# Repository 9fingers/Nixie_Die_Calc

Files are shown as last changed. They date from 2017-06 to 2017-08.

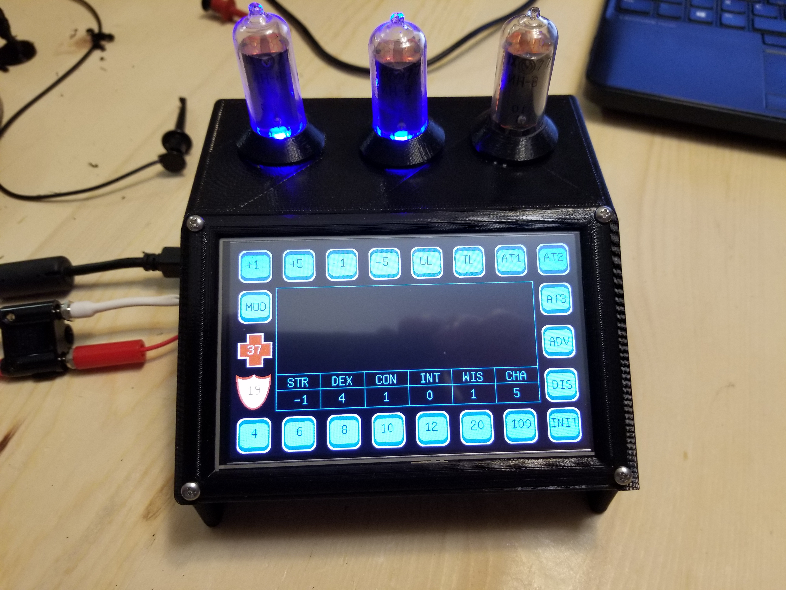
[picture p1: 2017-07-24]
20170722_200715[1].jpg

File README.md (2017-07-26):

# Nixie_Die_Calc<br />
An Arduino 2560 controlled die calculator that uses a 5.0" TFT for inputs, and displays the results on eh screen, and Nixie tubes. 

TFT control sketch is using the stock Adafrtuit RA8875 library.<br />

Videos of the project in its different states of flux. If you are curious as to how it functions watch the videos.https://www.youtube.com/user/BrnChknBrnCow

Hardware compatibility <br />
Nixie IN-18 <br />
IC 74141 Nixie control 16 pin chips<br />
Arduino MEGA 2560<br />
Adafruuit RA8875 Driver Chip (Part # 1590)<br />
Adafruit 5.0" TFT (800x480) (Part # 1596)<br />
Adafruit MicroSD card breakout board+ (Part # 254)<br />
<br />
Mentions:<br />
Nathaniel Burger: Software engineering manager.<br />
Assisted early on in the project by helping to explain the different building blocks while writing the code. Functions, variables (global and local), and plenty of other pointers that I failed to grasp at the time.

Cody Tappan: Embedded systems engineer. <br />
His code is commented in the project. Assisted with cursor tracking, and mapping the touch screen. 1024x1024 touch interface over a rectangular screen. 

Elliot Due: Electrical Engineer.<br />
Assisted with features that I decided to remove from the project as the scope of the project changed, and they were no longer needed. I learned a lot about board design, and reading electronics schematics. 

Eli Delia: Entrepreneur, graphics designer, jack of all trades.<br />
Modeled the dragon head for the final build. Introduced me to Fusion 360, and is defining the 3D print jobs for the final build. 

Last but not least, Conor Mooreman: Muse<br />
Conor was my inspiration to start this project, and to see it through to completion. So many times I have started projects like this and not completed them. Am truly happy to have this one so close to completion, can't wait for him to be able to try to use this. Conor has limited mobility, and dexterity, thus he cannot retrieve dice once they are rolled. He was using an app to roll dice which is just....well....boring. Hence the Nixie Die Calculator was born.</br>
</br>
</br>
</br>
On a side note this system can be used without the tubes, and only the touch screen display, and the SD card. 

Multiple web forums and thier contributors. <br />
Adafruit forums<br />
Arduino forums<br />
http://overskill.alexshu.com/saving-loading-settings-on-sd-card-with-arduino/

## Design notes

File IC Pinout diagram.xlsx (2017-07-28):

INPUT | INPUT | INPUT | INPUT | Lights | Wire
A | B | C | D | Cathode | Color
L | L | L | L | 0 | black
H | L | L | L | 1 | brown
L | H | L | L | 2 | red
H | H | L | L | 3 | orange
L | L | H | L | 4 | yellow
H | L | H | L | 5 | green
L | H | H | L | 6 | blue
H | H | H | L | 7 | purple
L | L | L | H | 8 | grey
H | L | L | H | 9 | white
10k Resistor to +180Vdc |  |  |  | Anode | grey
Wire Color | BLACK | BROWN | GREEN | YELLOW |  | BLUE | PURPLE | ORANGE
Nixie #'s | 0 | 1 | 5 | 4 | GND | 6 | 7 | 3
Chip Pins | 16 | 15 | 14 | 13 | 12 | 11 | 10 | 9
 | 74141
Chip Pins | 1 | 2 | 3 | 4 | 5 | 6 | 7 | 8
Nixie #'s | 8 | 9 | A | D | Vcc +3.3 | B | C | 2
Wire Color | GREY | WHITE |  |  |  |  |  | RED

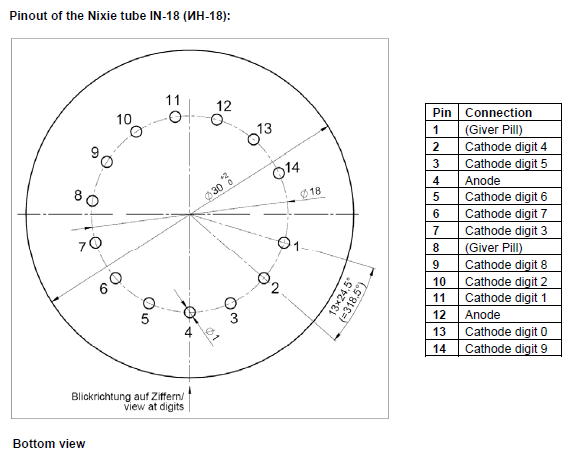
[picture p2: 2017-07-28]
in-18 Pinout.png

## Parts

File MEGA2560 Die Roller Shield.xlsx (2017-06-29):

Comment | Description | Designator | Footprint | LibRef | Quantity
AD_H |  | AD_H1 | Header 8x1 8.5mm | AD_H | 1
AD_L |  | AD_L1 | Header 8x1 8.5mm | AD_L | 1
Cap1 | Capacitor | C1, C4, C5, C8 | RAD-0.3 | Cap1 | 4
Cap2 | Capacitor | C2, C3, C6, C7 | CAPR5-4X5 | Cap2 | 4
Communication |  | COMMS1 | Header 8x1 8.5mm | Communication | 1
30V Zener | 1N5363B-TP | D1, D4 | Zener Diode | D Zener 30v 5w | 2
1N4002RLG | High Conductance Fast Diode | D2, D3, D5, D6 | DIODE | Diode 1N4002RLG | 4
1N4148 | High Conductance Fast Diode | D7 | DIODE | Diode 1N4148 | 1
IO_36 |  | DIGITAL1 | HEADER 36X 8MM | IO_36 | 1
ICSP |  | ICSP1 | ICSP | ICSP | 1
Relay-NL | TX2-L-3V | K1 | MODULE6 | Relay-DPST | 1
Header 13 | Header, 13-Pin | P1, P2, P3 | HDR1X13 | Header 13 | 3
Header 18X2 | Header, 18-Pin, Dual row | P4 | HDR2X18 | Header 18X2 | 1
Header 2 | Header, 2-Pin | P5 | HDR1X2 | Header 2 | 1
Header 3 | Header, 3-Pin | P6 | HDR1X3 | Header 3 | 1
Eye output | Header, 6-Pin | P7, P11 | HDR1X6 | Header 6 | 2
6.3 VDC HEATER POWER | Header, 2-Pin | P9 | HDR1X2 | Header 2 | 1
POWER |  | POWER1 | Header 6x1 8.5mm | POWER | 1
PWM_H |  | PWM_H1 | Header 8x1 8.5mm | PWM_H | 1
PWM_L |  | PWM_L1 | Header 8x1 8.5mm | PWM_L | 1
SS9014ABU-ND | SS9014ABU-ND | Q1, Q2 | TO-226-AA | Transistor 45V 0.1A | 2
TX2-L-3V | TX2-L-3V | Q3 | TO-226-AA | Transistor 45V 0.1A | 1
Res1 | Resistor, Resistor, Resistor, RES 2.7K OHM 1W 5% AXIAL, RES 2.7K OHM 1W 5% AXIAL | R1, R2, R5, R16, R26 | AXIAL-0.3 | Res1 | 5
Res2 | Resistor, Resistor, Resistor, RES 47k OHM 1W 5% AXIAL, RES 47k OHM 1W 5% AXIAL | R3, R4, R6, R9, R19 | AXIAL-0.3 | Res1, Res1, Res1, Res2, Res2 | 5
Res4 | RES 220k Ohm ±5% 1W | R7, R11, R17, R21 | AXIAL-0.3 - 220K | Res4 | 4
Res5 | RES 1M OHM 1W 5% AXIAL | R8, R10, R13, R18, R20, R23 | AXIAL-0.3 | Res5 | 6
RPot2 | 200k Ohm 0.5W, 1/2W Through Hole Thumbwheel Potentiometer Top Adjustment | R12, R22 | VR5-Top View | RPot2 | 2
RPot1 | 5k Ohm 0.5W, 1/2W Through Hole Thumbwheel Potentiometer Side Adjustment | R14, R25 | VR5 | RPot1 | 2
Res3 | RES 100k Ohm ±5% 0.25W, 1/4W | R15, R24 | AXIAL-0.3 | Res3 | 2
Res7 | RES 10k OHM .25W 5% AXIAL | R27 | AXIAL-0.3 | Res7 | 1
Res6 | RES 1k OHM .25W 5% AXIAL | R28 | AXIAL-0.3 | Res6 | 1
74141 | 16 Pin Dip Socket | U1, U2, U3 | PDIP16 | 74141 | 3

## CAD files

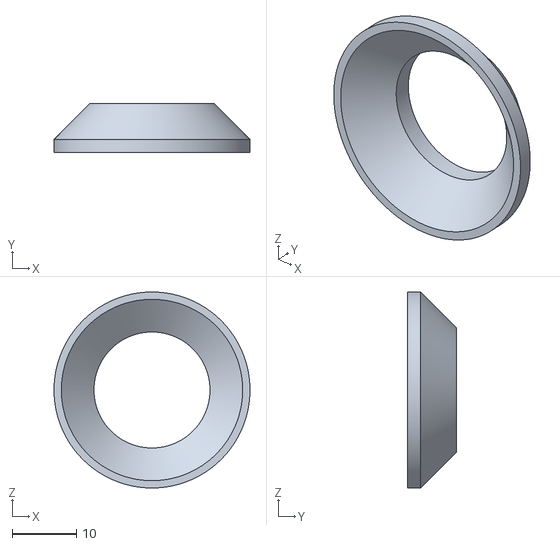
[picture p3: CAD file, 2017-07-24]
Tube Cone.stl
30.5 x 7.62 x 30.5

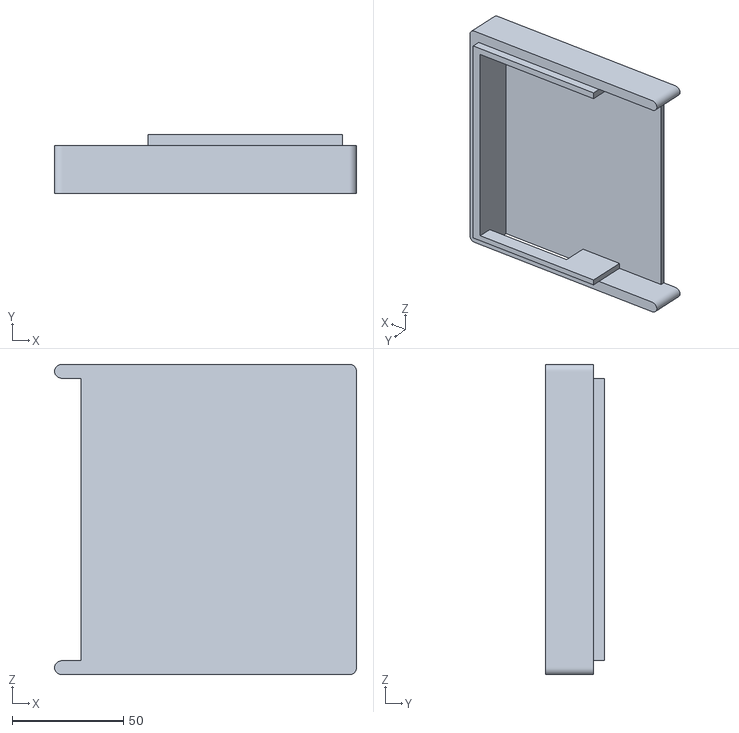
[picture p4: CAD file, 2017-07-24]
TFT Base.stl
135.9 x 26.7 x 139.7

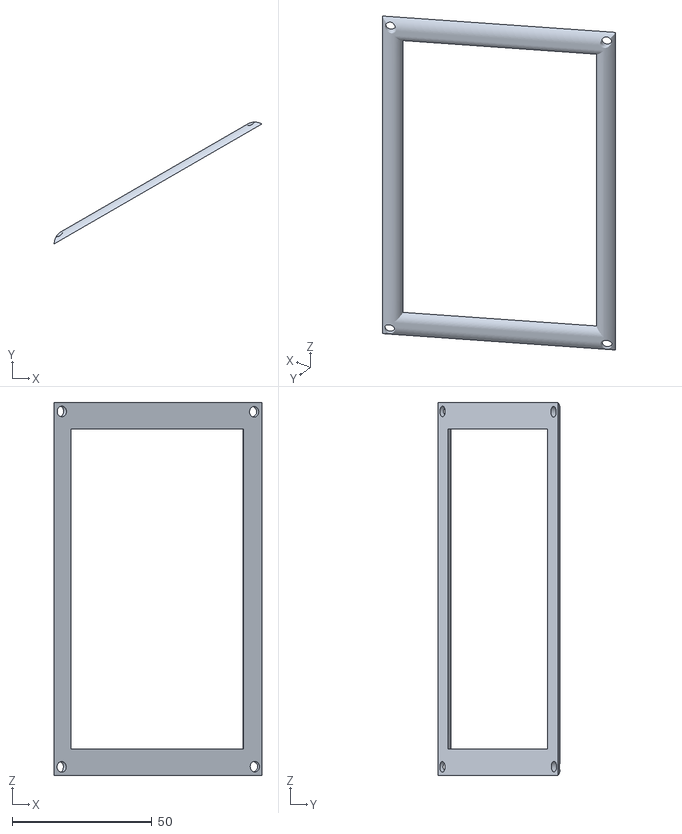
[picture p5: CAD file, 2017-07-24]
Bezel.stl
74.2 x 43.5 x 133.3

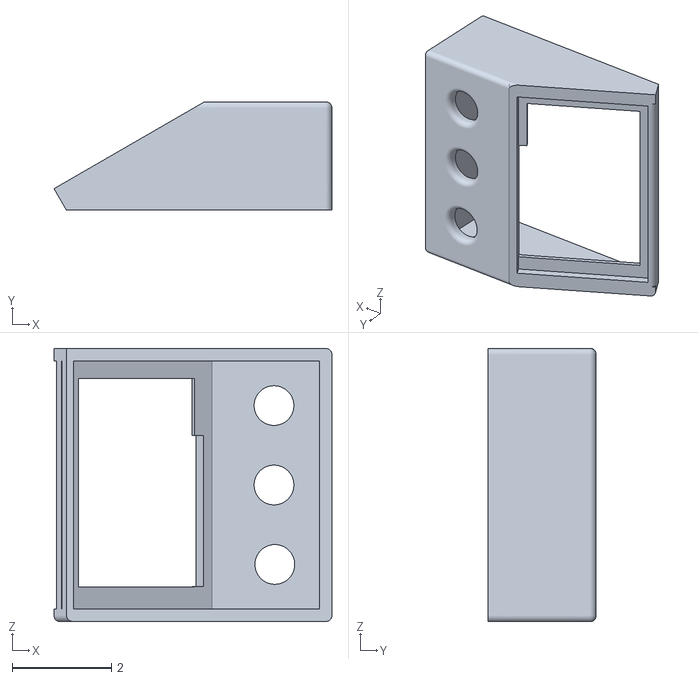
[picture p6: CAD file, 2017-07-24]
TFT Mount v3.stl
5.60 x 2.18 x 5.50

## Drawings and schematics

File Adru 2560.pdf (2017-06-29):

1

2

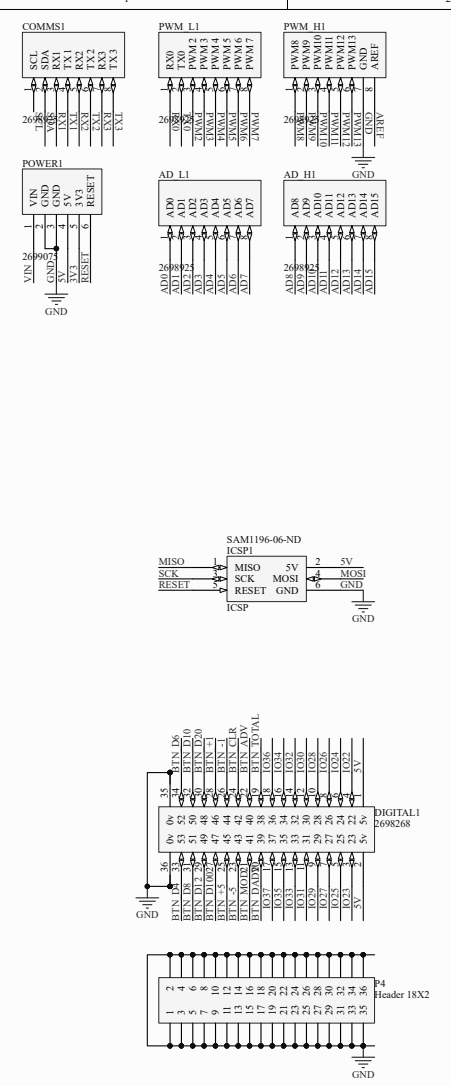
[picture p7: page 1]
VIN; GND; RESET; SCL; SDA; PWM2; PWM3; PWM4; PWM5; PWM6; PWM7; PWM8; PWM9; PWM10; PWM11; PWM12; PWM13; AREF; BTN_D6; BTN_D10; BTN_D20 BTN_+1 BTN_-1; BTN_CLR; BTN_ADV; BTN_TOTAL; BTN_D8; BTN_D12; BTN_D100 BTN_+5 BTN_-5; BTN_MOD; BTN_DADV; MISO 1; SCK 3; MOSI; RESET 5; SAM1196-06-ND ICSP1; ICSP; MISO SCK RESET; 5V MOSI GND; VIN 1; GND 2; GND 3 5V 4; RESET 6; POWER1; SCL 1; SDA 2 RX1 3; COMMS1; PWM 2 3; PWM 3 4; PWM 4 5; PWM 5 6; PWM 6 7; PWM 7 8; PWM_L1; PWM8 1; PWM9 2; PWM10 3 PWM11 4; PWM12 5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

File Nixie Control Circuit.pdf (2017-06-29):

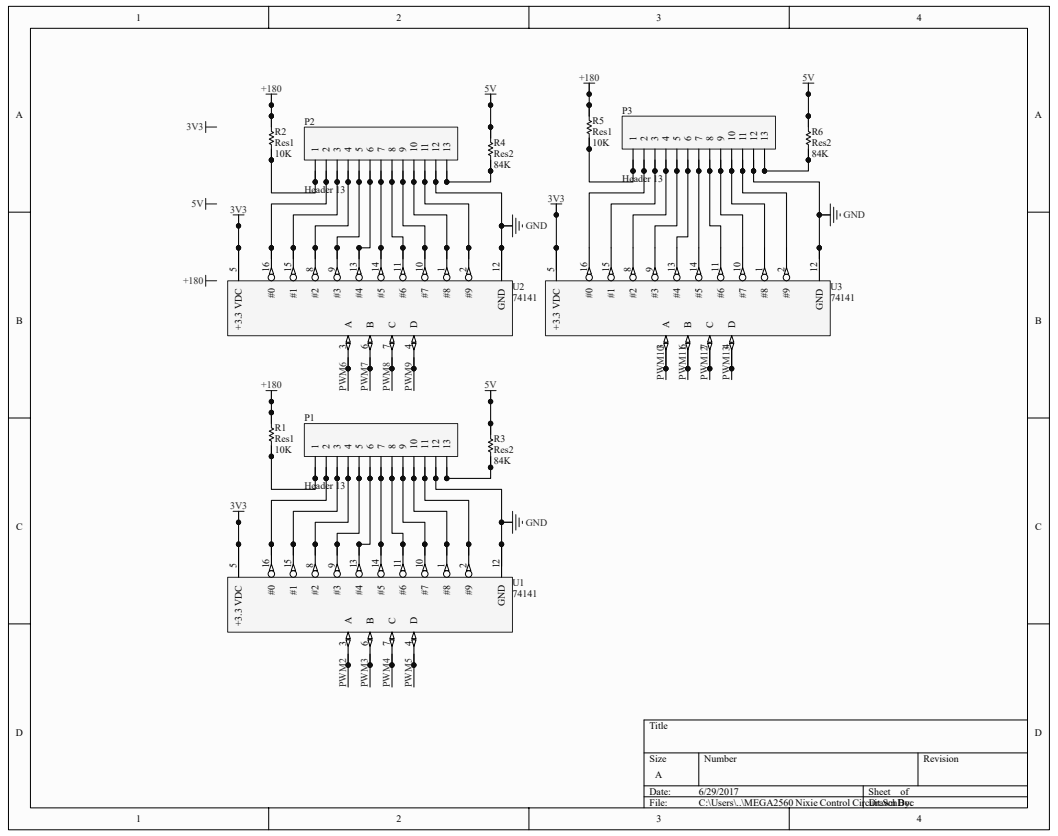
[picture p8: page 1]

Size A | Number | Revision

Date: 6/29/2017 | Sheet of
File: C:\Users\..\MEGA2560 Nixie Control Circuit.SchDoc Drawn By:

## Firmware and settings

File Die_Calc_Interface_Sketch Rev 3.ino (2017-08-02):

/******************************************************************
  This is an example for the Adafruit RA8875 Driver board for TFT displays
  ---------------> http://www.adafruit.com/products/1590
  It is tested to work with displays in the Adafruit shop. Other displays
  may need timing adjustments and are not guanteed to work.

  Adafruit invests time and resources providing this open
  source code, please support Adafruit and open-source hardware
  by purchasing products from Adafruit!

  Written by Limor Fried/Ladyada for Adafruit Industries.
  BSD license, check license.txt for more information.
  All text above must be included in any redistribution.
 ******************************************************************/
/*
  SD card code credit to:
  http://overskill.alexshu.com/saving-loading-settings-on-sd-card-with-arduino/
*/

#include <Arduino.h>
#include <SPI.h>
#include "Adafruit_GFX.h"
#include "Adafruit_RA8875.h"
#include <SD.h>
#include <Wire.h>
#include <Adafruit_STMPE610.h>

// tube control pins
// Tube ONES place
const int PIN_T1A = 22;         //PIN A
const int PIN_T1B = 23;         //PIN B
const int PIN_T1C = 24;         //PIN C
const int PIN_T1D = 25;         //PIN D

// Tube TENS Place
const int PIN_T2A = 26;         //PIN A
const int PIN_T2B = 27;         //PIN B
const int PIN_T2C = 28;         //PIN C
const int PIN_T2D = 29;         //PIN D

// Tube HUND Place
const int PIN_T3A = 30;         //PIN A
const int PIN_T3B = 31;         //PIN B
const int PIN_T3C = 32;         //PIN C
const int PIN_T3D = 33;         //PIN D

// For the Adafruit 5.0" TFT Screen, these are the default pins on a MEGA2560.
// SD Card CS = 53
// VN = +5vdc
// GND = Ground
// CLK = D52
// MISO = D50
// MOSI = D51
// pin 10 stays empty but is called in SD code
#define RA8875_INT 49 // was 22
#define RA8875_CS 48 //was 25
#define RA8875_RESET 9

//  Touchscreen map (actual values to 1024 scale)
//                    ACTUAL  ACTUAL  IDEAL   IDEAL
//                         MIN   MAX     MIN   MAX
#define X_CORRECTION_MAP    60,   980,  0,    1024
#define Y_CORRECTION_MAP    100,  940,  0,    1024

//*************
// Starting positions for the dieCursor used in eachDieRoll, void setup, etc...
#define CURSOR_START_X 110
#define CURSOR_START_Y 150

// Ending positions for the dieCursor
// Indicates how far we can write horizontally before
//  inserting new line (in pixels)
#define CURSOR_END_X 675
#define CURSOR_END_Y 380

// Incremental sizes for the characters
//  Cursor will move this many pixels for each character printed
#define CHARACTER_X_SIZE 10
#define CHARACTER_Y_SIZE 30

int txtStartx = 125;
int txtStarty = 301;

// pixel buffer forBMP Draw
#define BUFFPIXEL 20

Adafruit_RA8875 tft = Adafruit_RA8875(RA8875_CS, RA8875_RESET);
uint16_t tx, ty;

int stageNumber = 0;

// define placeholder columns
int VAR_Grand_Total_Ones;        // Grand total Ones column
int VAR_Grand_Total_Tens;        // Grand Total Tens Column
int VAR_Grand_Total_Hund;        // Grand total Hundreds column

// Global button sizing variables
int TRyStart = 10; // y start position
int DxSize = 75; // w size in pixels
int DySize = 75; // y size in pixels
int DRad = 15; // corner radius

// Top & side Rows Button Map positioning definitions
int MODxStart = 15; // X starting position Left vetical row
int TopiconSpace = 25; // X spacing between icons
int P1xStart = 15; // X starting position of bottom row
int P5xStart = ((P1xStart + DxSize) + TopiconSpace); // ****************************************
int M1xStart = ((P5xStart + DxSize) + TopiconSpace); //*****************************************
int M5xStart = ((M1xStart + DxSize) + TopiconSpace); // Next buton position based on first button in row, and previously defined variables.
int CLRxStart = ((M5xStart + DxSize) + TopiconSpace); //*****************************************
int TTLxStart = ((CLRxStart + DxSize) + TopiconSpace); //*****************************************
int ATK1xStart = ((TTLxStart + DxSize) + TopiconSpace); //*****************************************
int ATK2xStart = ((ATK1xStart + DxSize) + TopiconSpace); //*****************************************
int ATK3xStart = ((ATK1xStart + DxSize) + TopiconSpace); //Begin right vertical row of buttons
int ATK4xStart = ((ATK1xStart + DxSize) + TopiconSpace); //*****************************************
int ADVxStart = ((ATK1xStart + DxSize) + TopiconSpace); //*****************************************
int DISxStart = ((ATK1xStart + DxSize) + TopiconSpace); //*****************************************

//Bottom Row Button Maps positioning definitions
int BTMiconSpace = 25; // X spacing between icons
int BRyStart = 395; // y start position
int D4xStart = 15; // X starting position of bottom row
int D6xStart = ((D4xStart + DxSize) + BTMiconSpace); // ****************************************
int D8xStart = ((D6xStart + DxSize) + BTMiconSpace); // ****************************************
int D10xStart = ((D8xStart + DxSize) + BTMiconSpace); // Next buton position based on first button in roa, and previously defined variables.
int D12xStart = ((D10xStart + DxSize) + BTMiconSpace); // ****************************************
int D20xStart = ((D12xStart + DxSize) + BTMiconSpace); // ****************************************
int D100xStart = ((D20xStart + DxSize) + BTMiconSpace); // ****************************************
int INITxStart = ((D100xStart + DxSize) + BTMiconSpace); // ****************************************


// text display block definition for button labels
int TXTxStart = 100;
int TXTyStart = 100;
int TXTxWidth = 600;
int TXTyWidth = 280;

// setup file for character
File myFile;
// Saving Throw Stats (to be defined by user on startup)
int initiative = 0;
int armorClass = 0;
int STR = 0;
int strSave = 0;
int athletics = 0;
int DEX = 0;
int dexSave = 0;
int acrobatics = 0;
int slightOfHand = 0;
int stealth = 0;
int CON = 0;
int conSave = 0;
int INT = 0;
int intSave = 0;
int arcana = 0;
int history = 0;
int investigation = 0;
int nature = 0;
int religion = 0;
int WIS = 0;
int wisSave = 0;
int animalHandling = 0;
int insight = 0;
int medicine = 0;
int perception = 0;
int survival = 0;
int CHA = 0;
int charSave = 0;
int deception = 0;
int intimidation = 0;
int performance = 0;
int persuasion = 0;
int hitPoints = 0;
int atk1 = 0;
int atk2 = 0;
int atk3 = 0;
int atk4 = 0;
String charName = "PLAYER";
// end player stats

// Die sub totals
int VAR_4_Sum;                   // Total of all d4 rolled
int VAR_6_Sum;                   // Total of all d6 rolled
int VAR_8_Sum;                   // Total of all d8 rolled
int VAR_10_Sum;                  // Total of all d10 rolled
int VAR_12_Sum;                  // Total of all d12 rolled
int VAR_20_Sum;                  // Total of all d20 rolled
int VAR_100_Sum;                 // Total of all d100 rolled
int VAR_attackOneSum;
int VAR_attackTwoSum;
int VAR_attackThreeSum;
// Variable modifier to be added to roll if needed.
int VAR_Mod = 0;
// total of all dice and modifiers for applicable action
int VAR_Grand_Total;

// temporary place holder for sum of a singular die type (all D4 dice rolled, or all D5 dice rolled.
int DieRollSum = 0;
// number of dice in the dice bag
int buttonPushCounter = 0;

float xScale = 1024.0F / tft.width();
float yScale = 1024.0F / tft.height();

// begin Cody Tappan's  code
// Type used to track the position of the cursor
typedef struct {
  int xPos; // Horizontal position
  int yPos; // Vertical positon
} cursor;

// Instance of cursor,
// Used to track the cursor for printing die results
cursor dieCursor;
// end Cody Tappan's  code

// labels for stat blocks on mainstage
void statsLabel(int xstart, int ystart, String label)
{
  tft.textMode();
  tft.textEnlarge(1); // temporary increase to font size
  tft.textSetCursor(xstart, ystart); // defines starting text position for this code block
  tft.textColor(RA8875_CYAN, RA8875_BLACK);
  tft.print(label);
  tft.graphicsMode();
}

// prints stat values when called eiter mainstage or savestage
void statsPrint (int xstart, int ystart, int StatN)
{
  tft.textMode();
  tft.textEnlarge(1); // temporary increase to font size
  tft.textColor(RA8875_CYAN, RA8875_BLACK);
  tft.textSetCursor(xstart, ystart); // definnes the start position of the save number
  tft.print(StatN);
  tft.graphicsMode();
}

// clears the print area of all previously drawn text
// redraws text area bounding box
// redraws character save boxes, and labels
// rests cursor position to top left of text box
void resetCenterMainStage()
{
  // starting variables for drawing text on stage
  int txtStartx = 125;
  int txtStarty = 301;

  // Draw text boundry box on stage (Gobal variables defined at top of code structure)
  tft.fillRect(102, 102, 596, 280, RA8875_BLACK);
  // tft.fillRect (TXTxStart, TXTyStart, TXTxWidth, TXTyWidth, RA8875_BLACK);
  // Draw black background for text area
  tft.drawRect (TXTxStart, TXTyStart, TXTxWidth, TXTyWidth, RA8875_CYAN);

  // Draw horizontal dividers (local variables defined above)
  //           xStart/ystart/xEnd/yEnd
  tft.drawLine (100, 300, 700, 300, RA8875_CYAN); // top line of save label block
  tft.drawLine (100, 335, 700, 335, RA8875_CYAN); // middle line of save label block

  // Draw vertical Lines to define character save stats
  //           xStart/ystart/xEnd/yEnd
  tft.drawLine (200, 300, 200, 380, RA8875_CYAN);
  tft.drawLine (300, 300, 300, 380, RA8875_CYAN);
  tft.drawLine (400, 300, 400, 380, RA8875_CYAN);
  tft.drawLine (500, 300, 500, 380, RA8875_CYAN);
  tft.drawLine (600, 300, 600, 380, RA8875_CYAN);

  // Draw saving throw text identifiers
  statsLabel(txtStartx, txtStarty, "STR");
  statsLabel(txtStartx + 100, txtStarty, "DEX");
  statsLabel(txtStartx + 200, txtStarty, "CON");
  statsLabel(txtStartx + 300, txtStarty, "INT");
  statsLabel(txtStartx + 400, txtStarty, "WIS");
  statsLabel(txtStartx + 500, txtStarty, "CHA");

  // Draw saving throw values
  //          x / y / variable
  statsPrint (140, 340, STR);
  statsPrint (240, 340, DEX);
  statsPrint (340, 340, CON);
  statsPrint (440, 340, INT);
  statsPrint (540, 340, WIS);
  statsPrint (640, 340, CHA);

  // Cody Tappan's  code
  dieCursor.xPos = CURSOR_START_X;
  dieCursor.yPos = CURSOR_START_Y;
  // Cody Tappan's  code
}

// clears the print area of all previously drawn text
// redraws text area bounding box
// redraws character save boxes, and labels
// rests cursor position to top left of text box
// draws lines only no text or values
void drawSaveStage()
{
  // starting variables for drawing text on stage
  int txtStartx = 125;
  int txtStarty = 301;
  int TXTxStart = 100;
  int TXTyStart = 100;
  int TXTxWidth = 600;
  int TXTyWidth = 280;
  tft.fillRect(100, 100, 600, 285, RA8875_BLACK);
  // Home button for all saving throw pages
  tft.fillRoundRect(250, 220, 300, 60, DRad, RA8875_WHITE);
  tft.fillRoundRect(250 + 3 , 220 + 3, 300 - 6 , 60 - 6, DRad, RA8875_BLUE);
  tft.fillRoundRect(250 + 12 , 220 + 12, 300 - 24 , 60 - 24, DRad - 3, RA8875_CYAN);
  buttonlabel("Home", 338 , 220);

  // Draw text boundry box on stage
  tft.drawRect (TXTxStart, TXTyStart, TXTxWidth, TXTyWidth, RA8875_CYAN);

  // Draw horizontal dividers (local variables defined above)
  //           xStart/ystart/xEnd/yEnd
  tft.drawLine (100, 300, 700, 300, RA8875_CYAN); // top line of save label block
  tft.drawLine (100, 335, 700, 335, RA8875_CYAN); // middle line of save label block

  // Draw vertical Lines to define character save stats
  //           xStart/ystart/xEnd/yEnd
  tft.drawLine (200, 300, 200, 380, RA8875_CYAN);
  tft.drawLine (300, 300, 300, 380, RA8875_CYAN);
  tft.drawLine (400, 300, 400, 380, RA8875_CYAN);
  tft.drawLine (500, 300, 500, 380, RA8875_CYAN);
  tft.drawLine (600, 300, 600, 380, RA8875_CYAN);
}

void drawHealthStage()
{
  // starting variables for drawing text on stage
  int txtStartx = 125;
  int txtStarty = 301;
  int TXTxStart = 100;
  int TXTyStart = 100;
  int TXTxWidth = 600;
  int TXTyWidth = 280;
  // Home button for all saving throw pages
  tft.fillRoundRect(250, 220, 300, 60, DRad, RA8875_WHITE);
  tft.fillRoundRect(250 + 3 , 220 + 3, 300 - 6 , 60 - 6, DRad, RA8875_BLUE);
  tft.fillRoundRect(250 + 12 , 220 + 12, 300 - 24 , 60 - 24, DRad - 3, RA8875_CYAN);
  buttonlabel("Home", 338 , 220);

  // Draw text boundry box on stage
  tft.drawRect (TXTxStart, TXTyStart, TXTxWidth, TXTyWidth, RA8875_CYAN);

  // Draw horizontal dividers (local variables defined above)
  //           xStart/ystart/xEnd/yEnd
  tft.drawLine (100, 300, 700, 300, RA8875_CYAN); // top line of save label block
  tft.drawLine (100, 335, 700, 335, RA8875_CYAN); // middle line of save label block

  // Draw vertical Lines to define character save stats
  //           xStart/ystart/xEnd/yEnd
  tft.drawLine (200, 300, 200, 380, RA8875_CYAN);
  tft.drawLine (300, 300, 300, 380, RA8875_CYAN);
  tft.drawLine (400, 300, 400, 380, RA8875_CYAN);
  tft.drawLine (500, 300, 500, 380, RA8875_CYAN);
  tft.drawLine (600, 300, 600, 380, RA8875_CYAN);
}
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
void loop()
{
  Serial.print ("Begin VOid Loop");

  if (stageNumber == 0) {
    resetCenterMainStage();
    while (stageNumber == 0) {
      readMainStage();
      if (stageNumber > 0) {
        // tft.fillRect (100, 100, 600, 310, RA8875_RED); // clears screen for next stage
        return;
      }
    }
  }
  if (stageNumber == 1) {
    tft.fillRect (100, 100, 600, 280, RA8875_BLACK); // clears screen for next stage
    drawSaveStage();
    while (drawSaveStage) {
      // Draw saving throw text identifiers
      statsLabel(txtStartx - 15, txtStarty, "STREN");
      statsLabel(txtStartx + 85, txtStarty, "ATHLE");
      // Draw saving throw values
      //          x / y / variable
      statsPrint (140, 340, strSave);
      statsPrint (240, 340, athletics);
      readSTRSaveStage();
      if (stageNumber == 0) {
        return;
      }
    }
  }
  if (stageNumber == 2) {
    drawSaveStage();
    while (drawSaveStage) {
      // Draw saving throw text identifiers
      statsLabel(txtStartx - 10, txtStarty, "DEXT");
      statsLabel(txtStartx + 85, txtStarty, "ACROB");
      statsLabel(txtStartx + 185, txtStarty, "SoHND");
      statsLabel(txtStartx + 285, txtStarty, "STLTH");
      // Draw saving throw values
      //          x / y / variable
      statsPrint (140, 340, dexSave);
      statsPrint (240, 340, acrobatics);
      statsPrint (340, 340, slightOfHand);
      statsPrint (440, 340, stealth);
      readDEXSaveStage();
      if (stageNumber == 0) {
        tft.fillRect (100, 100, 600, 280, RA8875_BLACK); // clears screen for next stage
        return;
      }
    }
  }
  if (stageNumber == 3) {
    drawSaveStage();
    while (drawSaveStage) {
      // Draw saving throw text identifiers
      statsLabel(txtStartx, txtStarty, "CON");
      // Draw saving throw values
      //          x / y / variable
      statsPrint (140, 340, conSave);
      readCONSaveStage();
      if (stageNumber == 0) {
        tft.fillRect (100, 100, 600, 280, RA8875_BLACK); // clears screen for next stage
        return;
      }
    }
  }
  if (stageNumber == 4) {
    drawSaveStage();
    while (drawSaveStage) {
      // Draw saving throw text identifiers
      statsLabel(txtStartx - 15, txtStarty, "INTEL");
      statsLabel(txtStartx + 85, txtStarty, "ARCAN");
      statsLabel(txtStartx + 185, txtStarty, "HISTO");
      statsLabel(txtStartx + 285, txtStarty, "INVES");
      statsLabel(txtStartx + 385, txtStarty, "NATUR");
      statsLabel(txtStartx + 485, txtStarty, "RELIG");

      // Draw saving throw values
      //          x / y / variable
      statsPrint (140, 340, intSave);
      statsPrint (240, 340, arcana);
      statsPrint (340, 340, history);
      statsPrint (440, 340, investigation);
      statsPrint (540, 340, nature);
      statsPrint (640, 340, religion);
      readINTSaveStage();
      if (stageNumber == 0) {
        tft.fillRect (100, 100, 600, 280, RA8875_BLACK); // clears screen for next stage
        return;
      }
    }
  }
  if (stageNumber == 5) {
    drawSaveStage();
    while (drawSaveStage) {
      // Draw saving throw text identifiers
      statsLabel(txtStartx, txtStarty, "WIS");
      statsLabel(txtStartx + 85, txtStarty, "ANIML");
      statsLabel(txtStartx + 185, txtStarty, "INSIG");
      statsLabel(txtStartx + 285, txtStarty, "MEDIC");
      statsLabel(txtStartx + 385, txtStarty, "PERCP");
      statsLabel(txtStartx + 485, txtStarty, "SURVI");

      // Draw saving throw values
      //          x / y / variable
      statsPrint (140, 340, intSave);
      statsPrint (240, 340, animalHandling);
      statsPrint (340, 340, insight);
      statsPrint (440, 340, medicine);
      statsPrint (540, 340, perception);
      statsPrint (640, 340, survival);
      readWISSaveStage();
      if (stageNumber == 0) {
        tft.fillRect (100, 100, 600, 280, RA8875_BLACK); // clears screen for next stage
        return;
      }
    }
  }
  if (stageNumber == 6) {
    drawSaveStage();
    while (drawSaveStage) {
      // Draw saving throw text identifiers
      statsLabel(txtStartx, txtStarty, "CHA");
      statsLabel(txtStartx + 85, txtStarty, "DECEP");
      statsLabel(txtStartx + 185, txtStarty, "INTIM");
      statsLabel(txtStartx + 285, txtStarty, "PERFO");
      statsLabel(txtStartx + 385, txtStarty, "PERSU");

      // Draw saving throw values
      //          x / y / variable
      statsPrint (140, 340, charSave);
      statsPrint (240, 340, deception);
      statsPrint (340, 340, intimidation);
      statsPrint (440, 340, performance);
      statsPrint (540, 340, persuasion);
      //      Serial.println("Charisma block load test complete");
      //      Serial.println(persuasion);
      readCHASaveStage();
      if (stageNumber == 0) {
        tft.fillRect (100, 100, 600, 280, RA8875_BLACK); // clears screen for next stage
        return;
      }
    }
  }
  if (stageNumber == 7) {
    drawHealthStage();
    while (drawHealthStage) { //  copy savestage for base
      statsLabel(txtStartx, txtStarty, "HL+1");
      statsLabel(txtStartx + 100, txtStarty, "Hl+5");
      statsLabel(txtStartx + 200, txtStarty, "HL-1");
      statsLabel(txtStartx + 300, txtStarty, "HL-5");
      statsLabel(txtStartx + 400, txtStarty, "AC+1");
      statsLabel(txtStartx + 500, txtStarty, "AC-1");

      // Draw saving throw values
      //          x / y / variable
      //      statsPrint (140, 340, charSave);
      //      statsPrint (240, 340, deception);
      //      statsPrint (340, 340, intimidation);
      //      statsPrint (440, 340, performance);
      //      statsPrint (540, 340, persuasion);
      //      Serial.println("Charisma block load test complete");
      //      Serial.println(persuasion);
      readHealthStage(); // copy readSave Stage for base
      if (stageNumber == 0) {
        tft.fillRect (100, 100, 600, 280, RA8875_BLACK); // clears screen for next stage
        return;
      }
    }
  }
}

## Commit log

2017-07-13 Rename Die_Calc_Interface_Sketch.ino to Die_Calc_Interface_Sketch Rev 3.ino
    Change list
    Added functionality for
    Importing character settings via SD card
    saving throw rolls
    initiative rolls
    advantage rolls
    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
2017-07-26 Update Die_Calc_Interface_Sketch Rev 3.ino
    fixed:</br>
    athletics variable not loading</br>
    text not being erased before redrawing main stage.
    [Die_Calc_Interface_Sketch Rev 3.ino]
2017-07-28 Add files via upload
    Bottom view of the IN-18 tube and the pinout schematic.
2017-07-28 Add files via upload
    Useful breakout diagram of the IC and respective Nixie pins.
    [IC Pinout diagram.xlsx]
2017-07-30 Add files via upload
    Sample SETTINGS.TXT variable file.
2017-08-02 Update Die_Calc_Interface_Sketch Rev 3.ino
    fixed D10 touch not responding. Line of code for D10 was missing.
    [Die_Calc_Interface_Sketch Rev 3.ino]
